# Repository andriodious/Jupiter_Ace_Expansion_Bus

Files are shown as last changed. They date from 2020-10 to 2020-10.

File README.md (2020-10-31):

# Jupiter_Ace_Expansion_Bus
Provides a selection of Adapter boards for Jupiter Ace Bus Expansion

Created in KiCAD with Gerber files included.

There are 3 discrete boards in this repository:

* Ace to 50-Way - Adapts the Jupiter Ace external expansion bus to a 50-Way IDC header. 

* 50-Way to Ace - Adapts the 50-Way IDC header back an Ace-Bus format for legacy expansion peripherals

* Buffered 50-Way - Buffers address, data, clock and selected control lines with external input on Pin 50 'BufDir'. The BufDir signal is intended to be driven low by any given external device select signal. Each select signal must be connected via a logic IC, or schottky diode e.g. BAT85, to the BufDir input. Decoding of the select signals is expected to be 'one-hot' and handled by the expansion peripheral(s). This will allow the buffered interface board to correctly set the direction of the read data signals.

Note the conventional 50-way header pinout is 'reversed' on this design such that pin 1 corresponds to the leftmost pins on the IDC header, this was a concious choice in order to create more of a 1:1 connection with the Ace Bus.

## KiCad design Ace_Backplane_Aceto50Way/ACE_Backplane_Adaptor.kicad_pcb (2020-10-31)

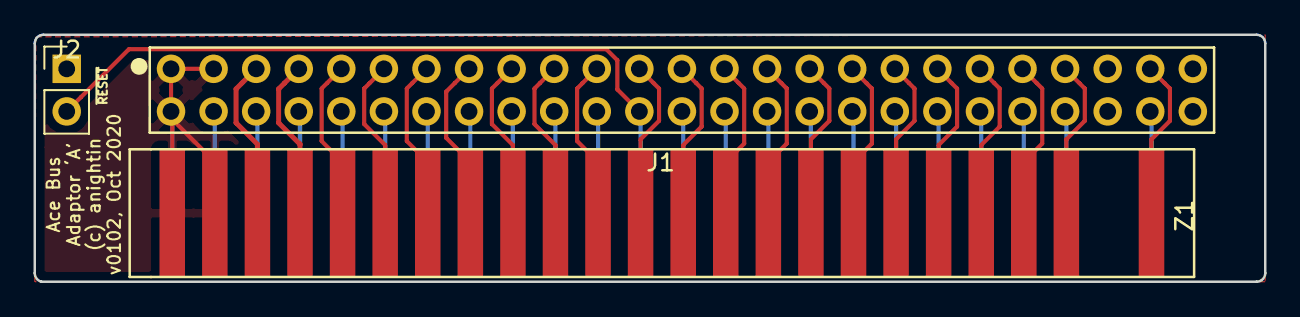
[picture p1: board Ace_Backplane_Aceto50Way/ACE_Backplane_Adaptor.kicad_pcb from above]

Board: 2 copper layers, 73.4 x 14.7 mm, 3 parts (0 on the bottom side), 44 nets.

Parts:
J1: AceBUS_Pin_Header; Ace_Bus_Pin_Header
J2: ~RESET_SW; PinHeader_1x02_P2.54mm_Vertical
Z1: AceBUS; Ace_Bus_Edge_Connector

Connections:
GND: J1.A1, J1.A2, J1.B1, J2.1, Z1.A1, Z1.A2, Z1.B1
unnamed: J1.A3, Z1.A3
unnamed: J1.A4, Z1.A4
unnamed: J1.A5, Z1.A5
unnamed: J1.A6, Z1.A6
unnamed: J1.A7, Z1.A7
unnamed: J1.A8, Z1.A8
unnamed: J1.A9, Z1.A9
unnamed: J1.A10, Z1.A10
unnamed: J1.A11, Z1.A11
unnamed: J1.A12, Z1.A12
unnamed: J1.A13, Z1.A13
unnamed: J1.A14, Z1.A14
unnamed: J1.A15, Z1.A15
unnamed: J1.A16, Z1.A16
unnamed: J1.A17, Z1.A17
unnamed: J1.A18, Z1.A18
unnamed: J1.A19, Z1.A19
unnamed: J1.A20, Z1.A20
unnamed: J1.A21, Z1.A21
unnamed: J1.A22, Z1.A22
unnamed: J1.A24, Z1.A24
unnamed: J1.B2, Z1.B2
unnamed: J1.B3, Z1.B3
unnamed: J1.B4, Z1.B4
unnamed: J1.B5, Z1.B5
unnamed: J1.B6, Z1.B6
unnamed: J1.B7, Z1.B7
unnamed: J1.B8, Z1.B8
unnamed: J1.B9, Z1.B9
unnamed: J1.B10, Z1.B10
unnamed: J1.B11, Z1.B11
unnamed: J1.B12, J2.2, Z1.B12
unnamed: J1.B13, Z1.B13
unnamed: J1.B14, Z1.B14
unnamed: J1.B15, Z1.B15
unnamed: J1.B16, Z1.B16
unnamed: J1.B17, Z1.B17
unnamed: J1.B18, Z1.B18
unnamed: J1.B19, Z1.B19
unnamed: J1.B20, Z1.B20
unnamed: J1.B21, Z1.B21
unnamed: J1.B22, Z1.B22
unnamed: J1.B24, Z1.B24

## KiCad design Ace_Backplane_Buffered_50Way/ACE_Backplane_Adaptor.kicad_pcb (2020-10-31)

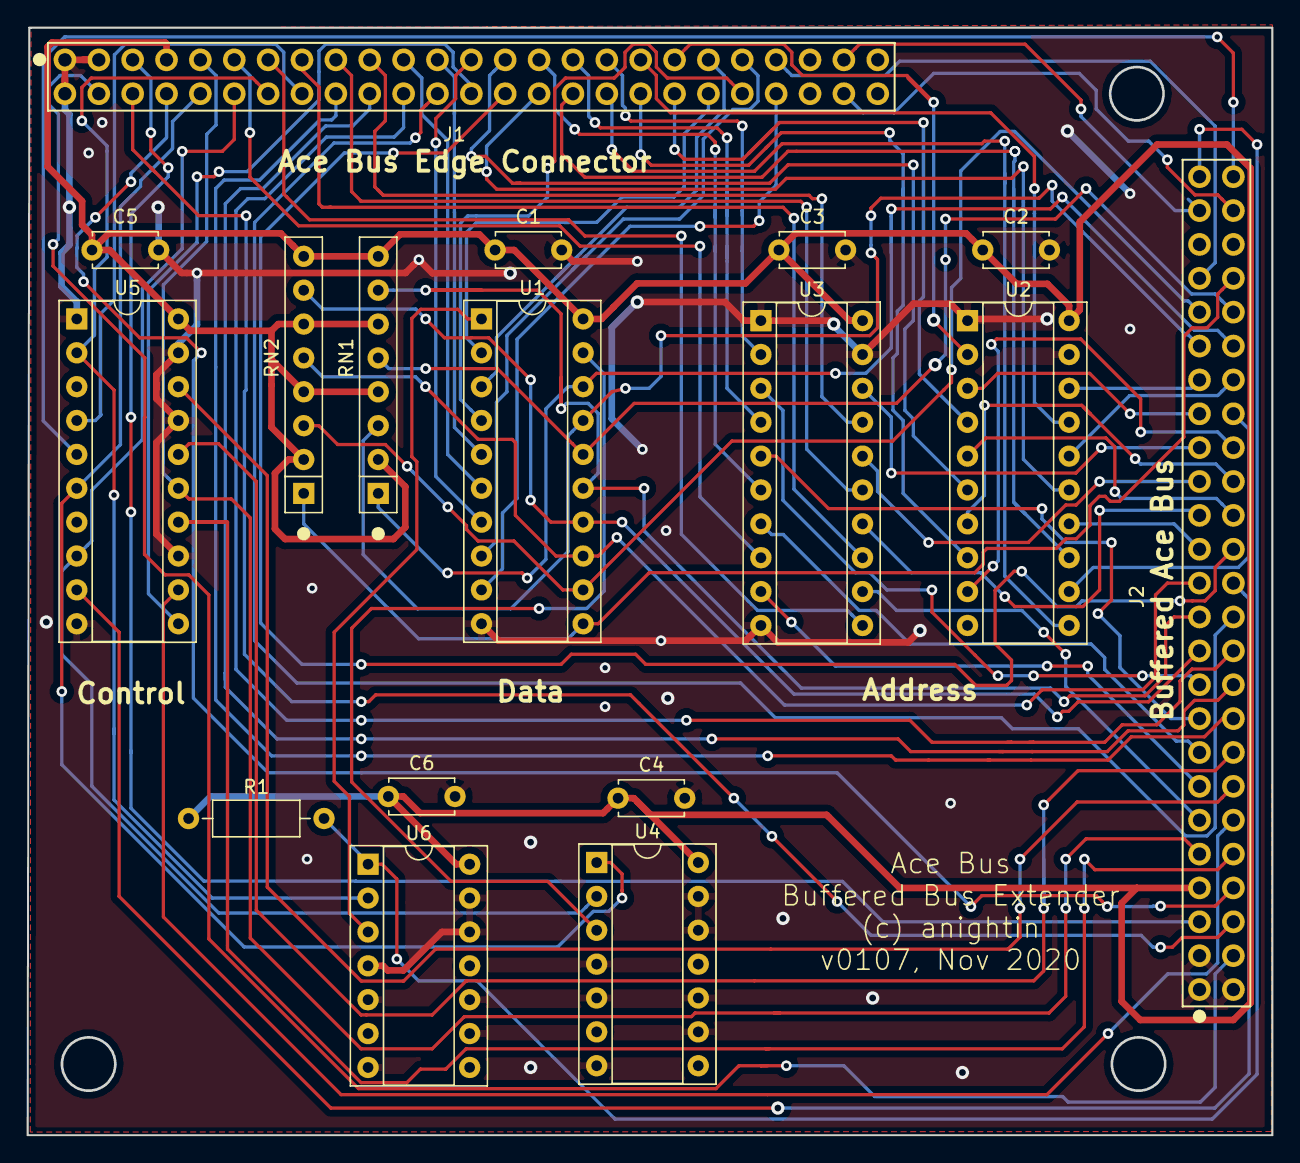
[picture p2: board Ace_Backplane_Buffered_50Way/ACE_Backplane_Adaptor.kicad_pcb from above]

Board: 2 copper layers, 93.3 x 83.1 mm, 17 parts (0 on the bottom side), 77 nets.

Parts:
C1, C2, C3, C4, C5, C6: 100n; C_Disc_D4.7mm_W2.5mm_P5.00mm
J1, J2: AceBUS_Pin_Header; Ace_Bus_Pin_Header
R1: 1K; R_Axial_DIN0207_L6.3mm_D2.5mm_P10.16mm_Horizontal
RN1, RN2: 4K7; R_Array_SIP8
U1: 74LS245; DIP-20_W7.62mm_Socket
U2, U3, U5: 74LS244; DIP-20_W7.62mm_Socket
U4: 74LS08; DIP-14_W7.62mm_Socket
U6: 74LS32; DIP-14_W7.62mm_Socket

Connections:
/+9V: J1.A3, J2.A3
/-: J1.A24, J2.A24
/A0: J1.A19, U2.2
/A0': J2.A19, U2.18
/A1: J1.B19, U2.4
/A1': J2.B19, U2.16
/A2: J1.A14, U2.6
/A2': J2.A14, U2.14
/A3: J1.B18, U2.8
/A3': J2.B18, U2.12
/A4: J1.B17, U2.11
/A4': J2.B17, U2.9
/A5: J1.B16, U2.13
/A5': J2.B16, U2.7
/A6: J1.B15, U2.15
/A6': J2.B15, U2.5
/A7: J1.A18, U2.17
/A7': J2.A18, U2.3
/A8: J1.A17, U3.2
/A8': J2.A17, U3.18
/A9: J1.A16, U3.4
/A9': J2.A16, U3.16
/A10: J1.A15, U3.6
/A10': J2.A15, U3.14
/A11: J1.A6, U3.8
/A11': J2.A6, U3.12
/A12: J1.A7, U3.11
/A12': J2.A7, U3.9
/A13: J1.A8, U3.13
/A13': J2.A8, U3.7
/A14: J1.A9, U3.15
/A14': J2.A9, U3.5
/A15: J1.A10, U3.17
/A15': J2.A10, U3.3
/BufDir: U1.1, U6.3
/CLK: J1.A5, J2.A5, U5.15
/CLK': J2.B25, U5.5
/D0: J1.B20, U1.2
/D0': J2.B20, RN1.1, U1.18
/D1: J1.A20, U1.3
/D1': J2.A20, RN1.3, U1.17
/D2: J1.B21, U1.4
/D2': J2.B21, RN1.5, U1.16
/D3: J1.A12, U1.5
/D3': J2.A12, RN1.7, U1.15
/D4: J1.A11, U1.6
/D4': J2.A11, RN2.7, U1.14
/D5: J1.A13, U1.7
/D5': J2.A13, RN2.5, U1.13
/D6: J1.A21, U1.8
/D6': J2.A21, RN2.3, U1.12
/D7: J1.B22, U1.9
/D7': J2.B22, RN2.1, U1.11
/ExtDir: J2.A25, R1.2, U6.1
/SysRD: U1.19, U4.3
/~ACEROMCS: J1.B24, J2.B24
/~BUSACK: J1.B9, J2.B9
/~BUSREQ: J1.B11, J2.B11
/~HALT: J1.B4, J2.B4
/~INT: J1.B2, J2.B2
/~IORQ: J1.B6, U4.2, U5.8
/~IORQ': J2.B6, U5.12
/~M1: J1.B13, U5.11
/~M1': J2.B13, U5.9
/~MREQ: J1.B5, U4.1, U5.6
/~MREQ': J2.B5, U5.14
/~NMI: J1.B3, J2.B3
/~RD: J1.B7, U5.2, U6.2
/~RD': J2.B7, U5.18
/~RESET: J1.B12, J2.B12
/~RFSH: J1.B14, J2.B14
/~WAIT: J1.B10, J2.B10
/~WE: J1.A22, J2.A22
/~WR: J1.B8, U5.4
/~WR': J2.B8, U5.16
GND: C1.2, C2.2, C3.2, C4.2, C5.2, C6.2, J1.A1, J1.A2, J1.B1, J2.A1, J2.A2, J2.B1, U1.10, U2.1, U2.10, U2.19, U3.1, U3.10, U3.19, U4.4, U4.5, U4.7, U4.9, U4.10, U4.12, U4.13, U5.1, U5.10, U5.13, U5.17, U5.19, U6.4, U6.5, U6.7, U6.9, U6.10, U6.12, U6.13
VCC: C1.1, C2.1, C3.1, C4.1, C5.1, C6.1, J1.A4, J2.A4, R1.1, RN1.2, RN1.4, RN1.6, RN1.8, RN2.2, RN2.4, RN2.6, RN2.8, U1.20, U2.20, U3.20, U4.14, U5.20, U6.14

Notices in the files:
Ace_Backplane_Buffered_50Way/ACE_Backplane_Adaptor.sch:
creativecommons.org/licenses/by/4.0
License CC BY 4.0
